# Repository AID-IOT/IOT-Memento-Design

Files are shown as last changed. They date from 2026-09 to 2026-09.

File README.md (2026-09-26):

# Memento

A keepsake PCB built at the **AICTE IDEA Lab, Poornima College of Engineering**.
It is a working board as well as a memento: a Seeed XIAO ESP32C3 drives four
WS2812B LEDs and reads a BMP280 pressure/temperature sensor, and serves the
readings on a web page over WiFi. The front silkscreen carries the AICTE IDEA
Lab and Poornima College logos.

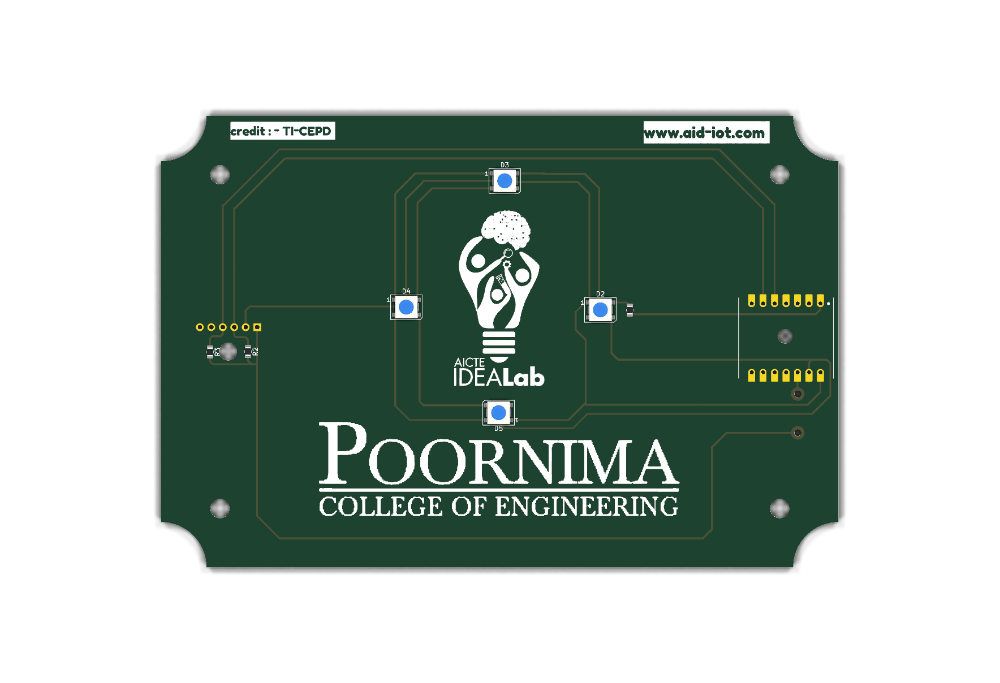
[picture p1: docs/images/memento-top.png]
Memento board, top side - 3D render of the finished PCB showing the AICTE IDEA Lab and Poornima College of Engineering logos on the front silkscreen


| | |
|---|---|
| Board | 150 × 100 mm, 1.6 mm, 2-layer |
| Controller | Seeed Studio XIAO ESP32C3 (RISC-V, WiFi 4 + BLE 5) |
| LEDs | 4 × WS2812B (5050 PLCC-4), daisy-chained |
| Sensor | GY-BMP280-3.3 module, I²C |
| Mounting | 4 × ⌀4.25 mm holes, 13 mm in from each edge |

## Repository layout

```
memento/
├── hw/          KiCad 10 project — schematic, PCB, project library, logo art
│   ├── memento.kicad_sch / .kicad_pcb / .kicad_pro
│   ├── memento.kicad_sym         project symbols
│   ├── memento.pretty/           project footprints
│   ├── assets/                   logo source images
│   └── tools/                    helper scripts (IPC, logo → footprint)
├── sw/          Firmware — builds in PlatformIO *and* opens in Arduino IDE
│   ├── platformio.ini
│   └── memento_fw/
│       ├── memento_fw.ino
│       ├── config.h              ← WiFi name and password go here
│       └── index_html.h          the web page
├── docs/        Project manual (.docx)
│   └── images/                   board renders used in this README
└── README.md
```

## Quick start

**1. Flash the board.** Plug the XIAO into USB-C, then either:

- *Arduino IDE* — open `sw/memento_fw/memento_fw.ino`, select board
  **XIAO_ESP32C3**, install the four Adafruit libraries, upload.
- *PlatformIO* — from `sw/`, run `pio run -t upload`.

Full steps, including the board-manager URL and library list, are in
[`sw/README.md`](sw/README.md).

**2. Set your WiFi.** Before uploading, edit `sw/memento_fw/config.h`:

```c
#define WIFI_SSID       "YOUR_WIFI_NAME"
#define WIFI_PASSWORD   "YOUR_WIFI_PASSWORD"
```

If that network cannot be joined the board starts its own hotspot
(`memento-setup` / `memento123`) so the page is still reachable.

**3. Open the page.** Open the serial monitor at **115200 baud**. It prints the
address it got:

```
Connected. Open http://192.168.1.42/  (or http://memento.local/)
BMP280 found at 0x76
HTTP server up on port 80
```

Browse to that address from any device on the same network. The page shows
temperature, pressure and altitude, refreshing every 2 seconds, and lets you set
the LED mode, colour, brightness and speed.

## Pin map

Taken from `hw/memento.kicad_sch`:

| Signal | XIAO pin | GPIO | Connects to |
|---|---|---|---|
| WS2812B data | D0 | 2 | R1 → D2.DIN → D3 → D4 → D5 |
| I²C SDA | D4 | 6 | U2.SDA, pulled up by R3 |
| I²C SCL | D5 | 7 | U2.SCL, pulled up by R2 |
| +5 V | 5V | — | WS2812B VDD ×4 |
| +3.3 V | 3V3 | — | BMP280 VCC, R2/R3 pull-ups |
| GND | GND | — | all |

## Bill of materials

| Ref | Qty | Part | Package | Notes |
|---|---|---|---|---|
| U1 | 1 | Seeed XIAO ESP32C3 | 14-pin module, 2.54 mm | Hybrid land pattern: headers or castellations |
| U2 | 1 | GY-BMP280-3.3 module | 6-pin, 2.54 mm | Runs from 3V3 |
| D2–D5 | 4 | WS2812B | 5050 PLCC-4 | Addressable RGB |
| R1 | 1 | 330 Ω | 0805 | Series on LED data line |
| R2, R3 | 2 | 4.7 kΩ | 0805 | I²C pull-ups to 3V3 |

> The resistor value fields in the schematic are still at their default
> (`R_US`). The values above are the intended ones — set them in the schematic
> before generating fabrication files.

## Building the PCB

Open `hw/memento.kicad_pro` in **KiCad 10**. The project carries its own symbol
and footprint libraries (`memento.kicad_sym`, `memento.pretty/`) registered
through the project-local `sym-lib-table` and `fp-lib-table`, so it opens
standalone with no external library setup.

The full build process — creating symbols, assigning footprints, importing the
logos to silkscreen, placement, routing and checks — is written up step by step
in the manual under [`docs/`](docs/).

The back side carries only the XIAO and BMP280 through-hole pads and the two
signal vias:

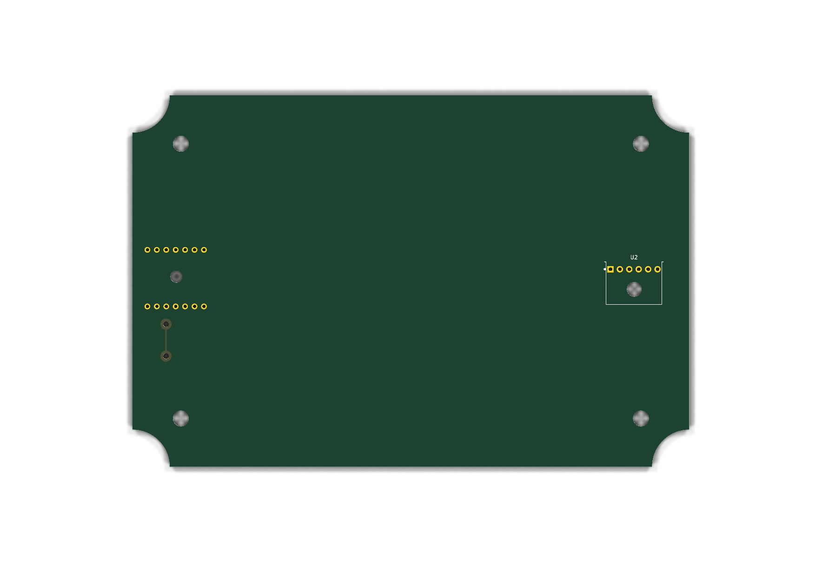
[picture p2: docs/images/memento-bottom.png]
Memento board, bottom side - 3D render showing the through-hole pads and vias


Both renders come straight from the board file, so they can be regenerated after
any layout change:

```bash
kicad-cli pcb render -o docs/images/memento-top.png \
  --side top --preset follow_pcb_editor --quality high \
  --background transparent -w 1800 -h 1240 hw/memento.kicad_pcb
```

Swap `--side top` for `--side bottom` for the other view. The
`follow_pcb_editor` preset matters: the default `follow_plot_settings` drops the
silkscreen, which renders the board as a blank rectangle with no logos.

## Documentation

| File | What it covers |
|---|---|
| [`docs/`](docs/) | Project manual (.docx) — full KiCad workflow, BOM, programming, usage |
| [`sw/README.md`](sw/README.md) | Firmware setup, libraries, HTTP API, hardware notes |

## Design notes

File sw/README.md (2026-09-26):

# memento — firmware

Firmware for the memento board: a **Seeed XIAO ESP32C3** driving **4× WS2812B**
LEDs and reading a **GY-BMP280-3.3** pressure/temperature module. It joins your
WiFi and serves a web page with the live readings and LED controls.

The same folder works two ways — open it in the Arduino IDE, or build it with
PlatformIO. Nothing needs converting.

```
sw/
├── platformio.ini        PlatformIO config (points src_dir at the sketch folder)
└── memento_fw/
    ├── memento_fw.ino    the sketch
    └── config.h          WiFi name/password and startup settings — edit this
```

## 1. Set your WiFi

Open `memento_fw/config.h` and change these two lines:

```c
#define WIFI_SSID       "YOUR_WIFI_NAME"
#define WIFI_PASSWORD   "YOUR_WIFI_PASSWORD"
```

If the board cannot join that network it starts its own hotspot instead
(`memento-setup`, password `memento123`), so the page is still reachable.
Both are configurable in the same file.

## 2a. Arduino IDE

1. **File → Preferences → Additional boards manager URLs**, add:
   `https://raw.githubusercontent.com/espressif/arduino-esp32/gh-pages/package_esp32_index.json`
2. **Tools → Board → Boards Manager**, install **esp32** by Espressif Systems.
3. **Tools → Board → ESP32 Arduino → XIAO_ESP32C3**.
4. **Tools → Manage Libraries**, install:
   - Adafruit NeoPixel
   - Adafruit BMP280 Library
   - Adafruit Unified Sensor
   - Adafruit BusIO
5. Open `memento_fw/memento_fw.ino`, edit `config.h`, upload.

## 2b. PlatformIO

From this `sw/` folder — libraries download automatically:

```
pio run              # build
pio run -t upload    # build and flash
pio device monitor   # serial log, 115200
```

## 3. Open the page

After upload, open the serial monitor at **115200**. It prints the address:

```
Joining "YOUR_WIFI_NAME" ....
Connected. Open http://192.168.1.42/  (or http://memento.local/)
BMP280 found at 0x76
HTTP server up on port 80
```

The page shows temperature, pressure and altitude (refreshing every 2 s) and
lets you set the LED mode, colour, brightness and animation speed.

## Pin map

Taken from the schematic (`../hw/memento.kicad_sch`), not assumed:

| Signal | XIAO pin | GPIO | Goes to |
|---|---|---|---|
| WS2812B data | D0 | **2** | R1 → D2.DIN → D3 → D4 → D5 (4 LEDs) |
| I²C SDA | D4 | **6** | U2 (BMP280) SDA |
| I²C SCL | D5 | **7** | U2 (BMP280) SCL |
| Power | 5V / GND | — | LEDs and sensor module |

## HTTP endpoints

| Route | Purpose |
|---|---|
| `GET /` | the control page |
| `GET /api/status` | JSON: sensor readings, LED state, network, uptime |
| `GET /api/led` | set LEDs — `mode`, `r`, `g`, `b`, `brightness`, `speed` |

`mode` is one of `solid`, `rainbow`, `breathe`, `chase`, `off`.
Example:

```
curl "http://memento.local/api/led?mode=solid&r=255&g=80&b=0&brightness=120"
```

## Notes on the hardware

- **The BMP280 module's VCC is wired to +5V on this board.** The GY-BMP280-**3.3**
  variant is a 3.3 V part with no on-board regulator, and the BMP280 is not 5 V
  tolerant. Check your module before powering it: if it has no regulator, move
  VCC to the XIAO's 3V3 pin. The firmware cannot protect against this.
- **CSB (pin 5) and SDO (pin 6) of the module are left unconnected.** Most
  GY-BMP280 boards pull CSB high (selects I²C) and SDO low (address `0x76`)
  with on-board resistors, so this usually works. The firmware probes `0x76`
  then `0x77` and keeps retrying every 5 s, so a late or intermittent sensor
  recovers without a reset. If it is never detected, tie CSB to VCC.
- The WS2812B chain runs at 5 V while the XIAO's data output is 3.3 V. That is
  below the 0.7 × VDD input threshold in the datasheet. It commonly works, and
  R1 sits in series on the data line, but a level shifter is the in-spec fix if
  the first LED misbehaves.
- GPIO2 is a strapping pin on the ESP32-C3. The WS2812B data input is
  high-impedance so it does not disturb boot mode.

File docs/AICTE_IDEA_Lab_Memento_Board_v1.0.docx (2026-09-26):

AICTE IDEA Lab Memento Board

v1.0

Project - Memento

From

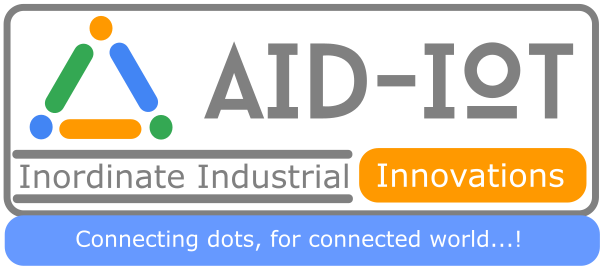
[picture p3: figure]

www.aid-iot.com

Inordinate Industrial Innovations Pvt Ltd.

BP-5, MLU Plots, DDA, Bindapur, Dwarka, New Delhi, 110059

Table of Contents

# 1. Introduction

The Memento is a keepsake circuit board built at the AICTE IDEA Lab, Poornima College of Engineering. It is a real working board as well as a souvenir: a Seeed Studio XIAO ESP32C3 module drives four addressable WS2812B RGB LEDs and reads air pressure and temperature from a BMP280 sensor module. The board joins a WiFi network and publishes the sensor readings on a small web page, which also lets you change the LED colour and animation from a phone or laptop.

The front of the board carries the AICTE IDEA Lab and Poornima College of Engineering logos in silkscreen.

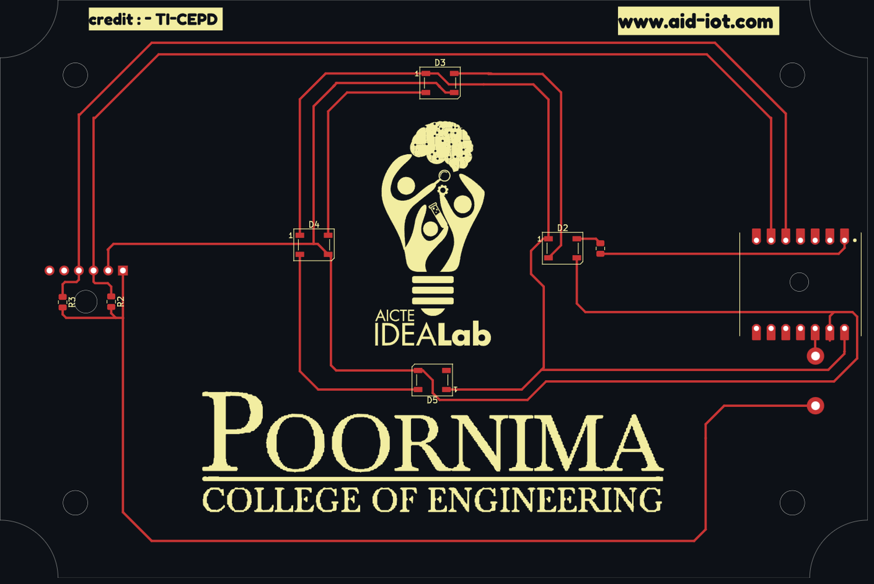
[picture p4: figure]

Front copper, silkscreen and board outline

## 1.1 Board summary

Item | Detail
Board size | 150 x 100 mm, 1.6 mm thick, 2 layers
Controller | Seeed Studio XIAO ESP32C3 (RISC-V, WiFi 4, BLE 5)
LEDs | 4 x WS2812B, 5050 PLCC-4, daisy chained
Sensor | GY-BMP280-3.3 module, I2C, pressure and temperature
Mounting | 4 x 4.25 mm holes, 13 mm in from every edge
Design tool | KiCad 10
Firmware | Arduino / ESP32 core, builds in Arduino IDE or PlatformIO

## 1.2 What you need

- KiCad 10 or newer, to open and edit the hardware design.
- Arduino IDE 2.x, or Visual Studio Code with the PlatformIO extension, to build the firmware.
- A USB-C cable that carries data, not a charge-only cable.
- A 2.4 GHz WiFi network. The ESP32-C3 does not support 5 GHz networks.
- A soldering iron and the parts in the bill of materials in section 4.2.

# 2. Repository Layout

The project is split into hardware, software and documentation:

memento/

hw/ KiCad project

memento.kicad_sch schematic

memento.kicad_pcb board layout

memento.kicad_pro project file - open this one

memento.kicad_sym project symbol library

memento.pretty/ project footprint library

assets/ logo source images

tools/ helper scripts

sw/ firmware

platformio.ini

memento_fw/

memento_fw.ino the sketch

config.h WiFi name and password

index_html.h the web page

docs/ this manual

README.md

Note The KiCad project carries its own symbol and footprint libraries, registered through the project-local sym-lib-table and fp-lib-table files. It opens on any machine with no extra library setup.

# 3. Hardware Design in KiCad

This section walks through how the board was built, in the order the work was done. Follow the same sequence to reproduce it or to make your own variant.

## 3.1 Opening the project

1. Start KiCad.
2. Choose File > Open Project.
3. Browse to the hw folder and open memento.kicad_pro.
4. The project manager lists the schematic and the PCB. Double-click either to open its editor.

## 3.2 Creating a schematic symbol

A symbol is the drawing of a part on the schematic, with its pins and pin numbers. KiCad ships thousands of symbols, but modules such as the XIAO ESP32C3 and the BMP280 breakout are not included, so they were drawn for this project and saved in the project library.

To create one:

5. In the schematic editor, choose Tools > Symbol Editor.
6. In the Libraries pane, select the project library (memento). If it is not listed, add it first with Preferences > Manage Symbol Libraries > Project Specific Libraries.
7. Choose File > New Symbol. Give it a name and a reference designator prefix - U for modules and integrated circuits, D for LEDs, R for resistors.
8. Draw the body with Place > Rectangle.
9. Add pins with Place > Pin. For every pin set the number, the name and the electrical type. The number must match the footprint pad number exactly, because that is the only link between the two.
10. Save the symbol.

Note Electrical type matters. Power inputs marked as Power Input, outputs as Output, and so on, are what lets the Electrical Rules Check catch mistakes such as two outputs driven onto the same net.

The symbols in this project and their pin numbering:

Symbol | Pins | Pin numbering
XIAO_ESP32C3 | 14 | 1-7 down the left edge (D0-D6), 8-14 up the right edge (D7-D10, 3V3, GND, 5V)
WS2812B | 4 | 1 VDD, 2 DOUT, 3 VSS, 4 DIN
BMP280_Module | 6 | 1 VCC, 2 GND, 3 SCL, 4 SDA, 5 CSB, 6 SDO

## 3.3 Creating a footprint

A footprint is the physical pattern of copper pads, silkscreen and courtyard that the part sits on. It must match the real part, so always work from the manufacturer drawing rather than from memory.

11. In the PCB editor, choose Tools > Footprint Editor.
12. Select the project library (memento) and choose File > New Footprint.
13. Place pads with Place > Pad. Set the pad number to match the symbol pin number, and set the shape, size and drill.
14. Draw the part outline on the F.Silkscreen layer, and the true body size on F.Fab.
15. Draw a courtyard on F.CrtYd, slightly larger than the part, so KiCad can warn when parts overlap.
16. Mark pin 1 clearly - a dot, a square pad or a chamfered corner.
17. Save the footprint.

The footprints used here:

Footprint | Type | Key dimensions
XIAO-ESP32C3-Hybrid | Through-hole + SMD | 14 holes, 2.54 mm pitch, 15.24 mm between rows, 0.889 mm drill, plus castellation pads
WS2812B_PLCC4_5.0x5.0mm | SMD | 4 pads 1.5 x 0.9 mm, body 5.0 x 5.0 mm
BMP280_Module_GY_6P_15x11.5mm | Through-hole | 6 holes, 2.54 mm pitch, 1.0 mm drill, outline 15 x 11.5 mm
R_0805_2012Metric | SMD | Standard KiCad 0805 land pattern

Note The XIAO footprint is a hybrid: every pin has a plated through-hole for header mounting and an outboard SMD pad for the castellated edge, so the module can be socketed or soldered flat.

## 3.4 Assigning footprints to symbols

Each symbol on the schematic must be told which footprint to use. There are two ways:

### Using the symbol properties

18. In the schematic, double-click the symbol.
19. Click the Footprint field, then the library browser button at the right.
20. Pick the footprint and click OK.

### Using the assignment tool

21. In the schematic editor, choose Tools > Assign Footprints.
22. The left pane lists libraries, the middle lists symbols, the right lists footprints.
23. Select a symbol, then double-click the footprint to assign it.
24. Click Apply, Save Schematic & Continue.

Note If you set a Footprint field inside the library symbol itself, every new copy you place already has the correct footprint and no assignment step is needed. That is how the symbols in this project are set up.

## 3.5 Importing an image onto the silkscreen

The two logos on this board were imported from ordinary image files. KiCad includes a converter for exactly this.

### Using the KiCad Image Converter

25. From the KiCad project manager, choose Tools > Image Converter.
26. Click Load Source Image and select the picture. PNG works well. A high-contrast image gives the best result.
27. Look at the Greyscale and Black and White preview tabs. Adjust the Threshold slider until the shape is clean and the detail you want is still visible.
28. Set the output size, either by entering the DPI or by setting the size in millimetres. Check the aspect ratio lock so the image is not stretched.
29. Under Output Format choose Footprint (.kicad_mod).
30. Under Board Layer for Outline choose Front Silkscreen.
31. Click Export to File and save the result inside your project footprint library folder, memento.pretty. KiCad only loads footprints that sit inside a folder listed in fp-lib-table, so a file saved anywhere else - the project root included - will not be found.
32. In the PCB editor, choose Place > Place Footprints (shortcut A), pick the new footprint from the memento library and click to place it. On KiCad 8 and earlier the same command is named Add Footprint.

Two things to fix after placing a logo footprint:

- Open its properties and tick "Not in schematic" (the board-only attribute), together with "Exclude from bill of materials" and "Exclude from position files". Without this, Update PCB from Schematic will offer to delete the logo because it has no matching symbol.
- Check the smallest details against your fabricator's minimum silkscreen line width, usually about 0.15 mm. Fine lines below that fill in when printed, so scale the logo up if detail is being lost.

Note The converter is monochrome. A colour logo becomes a single-colour silhouette: everything that is not background becomes ink, and enclosed background areas become gaps. Check the preview to confirm the result still reads correctly.

### If the new footprint does not appear in the chooser

Two causes account for nearly every case.

33. The file was saved outside the library folder. The Image Converter reuses the last folder you exported to, which is often the project root. A loose .kicad_mod file is never picked up on its own; move it into memento.pretty and it appears in the chooser under the memento library.
34. The library cache is stale. KiCad keeps an fp-info-cache file beside the project and does not always notice footprints added from outside the editor. Open Preferences > Manage Footprint Libraries and click OK to force a rescan, or close and reopen the PCB editor.

Note KiCad names the library entry after the file, not after the name written inside it. A file saved as aid_iot_logo.kicad_mod is listed as aid_iot_logo even though the converter wrote (footprint "LOGO") on the first line. Rename the two to match so the library stays readable.

### Putting a logo on the schematic

The same converter can emit a schematic symbol instead: choose Symbol (.kicad_sym) under Output Format and export. A symbol library is a single .kicad_sym file rather than a folder, and it has to be registered before the symbol chooser will list it. In the schematic editor open Preferences > Manage Symbol Libraries, add the file on the Project Specific Libraries tab and give it a nickname; this writes a line into sym-lib-table beside the project.

A logo symbol has no pins. Mark it Exclude from bill of materials and Exclude from board in its properties so it never reaches the netlist.

### Cleaner outlines with logo2fp.py

The Image Converter works from a black and white threshold, which rounds off fine detail. This project also carries hw/tools/logo2fp.py, which traces the ink boundary directly and writes one filled polygon per outline, folding enclosed gaps back into their parent shape. It holds edges better at small sizes. Run it from the hw folder:

python tools/logo2fp.py assets/logo_poornima.png \

memento.pretty/Logo_Poornima_80x48.kicad_mod \

Logo_Poornima_80x48 80.0 400 F.SilkS 5:3

The arguments are the source image, the output path, the footprint name and the width in millimetres, followed by the optional trace resolution, target layer and box aspect ratio. Both logos already on this board were produced this way. The script needs numpy and Pillow.

### Placing an image for reference only

If you only want a picture as a guide - a mechanical drawing or a layout sketch - use Place > Place Reference Images in the PCB or schematic editor (named Add Image on KiCad 8 and earlier). Reference images are shown in the editor but are not plotted to the fabrication outputs, so they never appear on the finished board.

## 3.6 Updating the PCB from the schematic

The schematic is the source of truth. The board is brought into line with it rather than edited independently.

35. Draw the circuit in the schematic editor. Place symbols with Place > Add Symbol, wire them with Place > Wire, and add power symbols for the supply nets.
36. Annotate the sheet with Tools > Annotate Schematic so every part gets a unique reference designator.
37. Run the Electrical Rules Check with Inspect > Electrical Rules Checker and clear anything real.
38. Save the schematic.
39. In the PCB editor choose Tools > Update PCB from Schematic, or press F8.
40. Review the list of changes and click Update PCB. New footprints appear at the cursor for you to place.

Note KiCad links each symbol to its footprint by a hidden unique identifier, not by the reference designator. That is why renaming a part does not break the link, and why a footprint added directly to the board with no symbol behind it must be marked board-only.

## 3.7 Component placement

Placement decides how easy the routing will be. Work from the fixed constraints outwards.

41. Place the parts whose position is dictated by the enclosure or by the user first. Here the XIAO sits at the right-hand edge so the USB-C connector is reachable.
42. Place the parts that must sit near something else. The pull-up resistors R2 and R3 sit next to the BMP280 module, and the series resistor R1 sits next to the XIAO data pin.
43. Place the decorative elements - here the two logos and the text labels - and keep them clear of the parts.
44. Spread the four WS2812B LEDs around the logo so the light is even.
45. Use Edit > Properties or the Position fields to set exact coordinates where symmetry matters.

Useful tools while placing:

- Press M to move a part, R to rotate it, F to flip it to the other side of the board.
- The ratsnest - the thin lines showing what still needs connecting - shows when a move will make routing shorter.
- View > Grid, and the grid selector in the toolbar, keep parts on tidy coordinates.
- Inspect > Design Rules Checker reports courtyard overlaps if two parts are placed too close.

## 3.8 Routing

Routing draws the copper tracks that carry the signals.

46. Select the copper layer to work on in the Layers pane - F.Cu for the front, B.Cu for the back.
47. Choose Route > Route Single Track, or press X, then click a pad to start.
48. Click to place corners and double-click to finish on the destination pad. The ratsnest line for that connection disappears once it is routed.
49. Press V while routing to drop a via and continue on the other layer.
50. Set track widths under File > Board Setup > Design Rules > Net Classes. Power nets are usually given wider tracks than signals.
51. When everything is routed, run the Design Rules Checker and confirm there are no unconnected items left.

Guidance that applies to this board:

- Give the +5 V and GND tracks more width than the signal tracks. They carry the LED current, which rises with brightness.
- Keep the WS2812B data chain going in one direction: XIAO to D2, D2 to D3, D3 to D4, D4 to D5. Each LED regenerates the signal for the next.
- Keep the I2C pair SDA and SCL reasonably short and run them together.
- Leave clearance around the mounting holes so a screw head or standoff cannot touch copper.

## 3.9 Board outline and mounting holes

The board shape is drawn on the Edge.Cuts layer. Anything on that layer is cut by the fabricator.

52. Select the Edge.Cuts layer.
53. Draw the outline with Place > Line, Place > Rectangle or Place > Arc. It must form one closed shape with no gaps.
54. For mounting holes, either place a circle on Edge.Cuts, or place a mounting-hole footprint from the KiCad MountingHole library if you want a plated hole with a pad.
55. Check the result with View > 3D Viewer, which shows the board exactly as it will be cut.

This board is 150 x 100 mm with rounded inside corners and four mounting holes of 4.25 mm diameter, each set 13 mm in from both nearest edges so the pattern is symmetric about the centre of the board.

## 3.10 Electrical and design rule checks

Two separate checks must both be clean before sending the board out.

### Electrical Rules Check - the schematic

56. In the schematic editor choose Inspect > Electrical Rules Checker.
57. Click Run ERC.
58. Work through each message. Common ones are unconnected pins, and power input pins with nothing driving them - which is normal until you add power flags.

### Design Rules Check - the board

59. In the PCB editor choose Inspect > Design Rules Checker.
60. Tick "Report all errors for tracks" and click Run DRC.
61. Fix clearance violations, unconnected items and silkscreen overlaps.
62. Pay attention to "unconnected items". Any number other than zero means part of the circuit is not routed.

Note Set the clearance and track width rules to match your fabricator before routing, under File > Board Setup > Design Rules > Constraints. Fixing a board designed to the wrong rules is far more work than setting them first.

## 3.11 Fabrication outputs

When both checks are clean, produce the files the factory needs.

63. Choose File > Fabrication Outputs > Gerbers. Select the layers and export to a gerbers folder.
64. Choose File > Fabrication Outputs > Drill Files and export into the same folder.
65. Zip the folder and send it to the fabricator.
66. For assembly, also export the position file from File > Fabrication Outputs > Component Placement, and the bill of materials from the schematic editor with Tools > Generate BOM.

# 4. Project Details

## 4.1 Pin map

These are the actual connections in the schematic. The firmware uses exactly these pins.

Signal | XIAO pin | GPIO | Connects to
WS2812B data | D0 | 2 | R1, then D2.DIN, then D3, D4, D5 in a chain
I2C SDA | D4 | 6 | U2 SDA, pulled up to 3V3 by R3
I2C SCL | D5 | 7 | U2 SCL, pulled up to 3V3 by R2
+5 V | 5V | - | VDD of all four WS2812B LEDs
+3.3 V | 3V3 | - | BMP280 VCC and the two I2C pull-ups
GND | GND | - | Every part

Note The BMP280 module runs from 3.3 V, not 5 V. The GY-BMP280-3.3 has no on-board regulator and the BMP280 is not 5 V tolerant, so connecting it to 5 V damages it.

## 4.2 Bill of materials

Ref | Qty | Part | Package | Notes
U1 | 1 | Seeed Studio XIAO ESP32C3 | 14-pin module, 2.54 mm | Headers or castellated mounting
U2 | 1 | GY-BMP280-3.3 module | 6-pin, 2.54 mm | Pressure and temperature, I2C
D2, D3, D4, D5 | 4 | WS2812B | 5050 PLCC-4 | Addressable RGB LED
R1 | 1 | 330 ohm | 0805 | Series resistor on the LED data line
R2, R3 | 2 | 4.7 k ohm | 0805 | I2C pull-ups to 3V3
- | 4 | M4 screw and standoff | - | For the 4.25 mm mounting holes
- | 1 | USB-C cable | - | Must carry data, not charge only

Note The resistor value fields in the schematic are still at their default and read R_US. The values above are the intended ones - set them in the schematic before generating fabrication files or before ordering parts.

## 4.3 Assembly notes

67. Solder the four WS2812B LEDs first. They are surface mount and easiest to reach while the board is otherwise empty. Watch the orientation - the cut corner or the marking on the package matches pin 1 on the footprint.
68. Solder the three 0805 resistors.
69. Fit a 7-pin header strip on each side for the XIAO, or solder the module directly onto the castellated pads.
70. Fit a 6-pin header for the BMP280 module.
71. Check for solder bridges before applying power, especially across the fine-pitch LED pads.
72. Power the board over USB-C and confirm the LEDs light before going further.

# 5. Programming the Board

The firmware lives in the sw folder. It is written so that the same files open in the Arduino IDE and build under PlatformIO, with nothing to convert between them.

## 5.1 Firmware layout

File | Purpose
sw/platformio.ini | PlatformIO settings. Points at the sketch folder so both tools share one copy of the code.
sw/memento_fw/memento_fw.ino | The sketch - setup, main loop, sensor reading, LED animation and web server.
sw/memento_fw/config.h | WiFi name and password, and the start-up LED settings. This is the file you edit.
sw/memento_fw/index_html.h | The web page, stored as text in program memory.

## 5.2 Setting the WiFi name and password

Open sw/memento_fw/config.h and change these two lines:

#define WIFI_SSID "YOUR_WIFI_NAME"

#define WIFI_PASSWORD "YOUR_WIFI_PASSWORD"

If the board cannot join that network within 20 seconds it starts its own hotspot instead, so the page is still reachable:

#define AP_SSID "memento-setup"

#define AP_PASSWORD "memento123"

Connect a phone or laptop to that hotspot and open http://192.168.4.1/ to reach the page.

Note The ESP32-C3 only joins 2.4 GHz networks. If your router broadcasts one name for both 2.4 GHz and 5 GHz, and the board will not connect, try a separate 2.4 GHz network name or a phone hotspot set to 2.4 GHz.

## 5.3 Method A - Arduino IDE

### One-time setup

73. Open File > Preferences.
74. In "Additional boards manager URLs" paste: https://raw.githubusercontent.com/espressif/arduino-esp32/gh-pages/package_esp32_index.json
75. Click OK, then open Tools > Board > Boards Manager.
76. Search for esp32 and install "esp32 by Espressif Systems".
77. Open Tools > Manage Libraries and install these four: Adafruit NeoPixel, Adafruit BMP280 Library, Adafruit Unified Sensor, Adafruit BusIO.

### Every time

78. Open sw/memento_fw/memento_fw.ino. The Arduino IDE shows config.h and index_html.h as extra tabs, because they sit in the same folder as the sketch.
79. Edit the WiFi name and password on the config.h tab.
80. Choose Tools > Board > ESP32 Arduino > XIAO_ESP32C3.
81. Plug in the board and choose its port under Tools > Port.
82. Click Upload.

Note If no port appears, hold the BOOT button on the XIAO, tap RESET, then release BOOT. The board enters its bootloader and the port appears. Also check the USB cable carries data - charge-only cables are a common cause.

## 5.4 Method B - PlatformIO

From the sw folder. PlatformIO downloads the toolchain and the libraries by itself on the first build.

pio run build only

pio run -t upload build and flash the board

pio device monitor open the serial log at 115200 baud

In Visual Studio Code, open the sw folder and use the PlatformIO toolbar buttons at the bottom of the window instead of typing the commands.

# 6. Checking the Web Page

## 6.1 Finding the address

83. Keep the board plugged into USB after uploading.
84. Open the serial monitor - in the Arduino IDE, Tools > Serial Monitor; in PlatformIO, pio device monitor.
85. Set the speed to 115200 baud.
86. Press the RESET button on the XIAO so you see the start-up messages from the beginning.

You should see something like this:

memento starting

BMP280 found at 0x76

Joining "YOUR_WIFI_NAME" ....

Connected. Open http://192.168.1.42/ (or http://memento.local/)

HTTP server up on port 80

87. Type that address into a browser on any device connected to the same network.

Note http://memento.local/ works on most phones and on Windows, macOS and Linux machines with mDNS. If it does not resolve on your network, use the numeric address instead - it always works.

## 6.2 What the page shows

The page has two parts.

The BMP280 panel shows three live readings, refreshed every two seconds:

- Temperature, in degrees Celsius.
- Pressure, in hectopascal.
- Altitude, in metres. This is calculated from the pressure, so it is only as accurate as the sea-level pressure set in config.h.

If the sensor is not detected the panel turns amber and the readings show as dashes. The firmware keeps retrying every five seconds, so a loose module starts working again as soon as it is reseated, without a reset.

The WS2812B panel controls the four LEDs:

Control | What it does
Solid | All four LEDs show the chosen colour
Rainbow | Colours cycle smoothly around the chain
Breathe | The chosen colour fades up and down
Chase | A bright dot runs around the chain
Off | All LEDs off
Colour | Colour picker, used by Solid, Breathe and Chase
Brightness | 0 to 255
Speed | Milliseconds per animation step - lower is faster

The line at the bottom of the page shows whether the board is on your WiFi or running its own hotspot, its address, the signal strength, how long it has been running, and the sensor address.

## 6.3 HTTP API

The page is driven by two simple endpoints, which you can also call yourself for testing or to connect the board to something else.

Route | Purpose
GET / | The control page
GET /api/status | JSON with the sensor readings, LED state, network details and uptime
GET /api/led | Sets the LEDs. Parameters: mode, r, g, b, brightness, speed

For example, to set all four LEDs to solid orange at medium brightness:

curl "http://memento.local/api/led?mode=solid&r=255&g=80&b=0&brightness=120"

And to read the sensor from a script:

curl http://memento.local/api/status

# 7. Troubleshooting

Symptom | What to check
No serial port appears | Use a data USB cable. Hold BOOT, tap RESET, release BOOT to force the bootloader.
Upload fails part way | Close the serial monitor first - it holds the port open. Then retry.
Board never joins WiFi | The network must be 2.4 GHz. Check the name and password for typing mistakes and stray spaces. Watch the serial log for the reason.
Page will not open | Use the numeric address from the serial log rather than memento.local. Confirm your phone or laptop is on the same network.
BMP280 not detected | The serial log reports it at start-up. Check the 6-pin header solder joints, that VCC goes to 3V3, and that CSB is not pulled low. The firmware probes both 0x76 and 0x77.
Sensor readings look wrong | Altitude depends on SEA_LEVEL_HPA in config.h. Set it to your local sea-level pressure for a meaningful altitude.
LEDs stay dark | Check the brightness is not zero and the mode is not Off. Confirm 5 V reaches the first LED and that R1 is fitted.
Only the first LED works | The chain is broken after it. Check the DOUT to DIN joint between that LED and the next.
LED colours are wrong or flicker | The data line runs at 3.3 V into 5 V parts, which is below the datasheet threshold. It usually works, but a level shifter is the proper fix.

Inordinate Industrial Innovations Pvt Ltd.

Restricted www.aid-iot.com

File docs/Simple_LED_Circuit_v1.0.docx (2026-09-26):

Simple LED Circuit

v1.0

Project - Memento

From


www.aid-iot.com

Inordinate Industrial Innovations Pvt Ltd.

BP-5, MLU Plots, DDA, Bindapur, Dwarka, New Delhi, 110059

Table of Contents

# 1. Aim

To build a simple series circuit in which a single light emitting diode (LED) is lit from an external power supply, with the current limited by one series resistor, and to verify the resistor value by measurement and calculation.

# 2. Components Required

Ref | Qty | Component | Specification
D1 | 1 | LED, 5 mm | Red, forward voltage about 2.0 V, forward current 10 to 20 mA
R1 | 1 | Resistor | 330 ohm, 1/4 W, 5 percent tolerance
J1 | 1 | 2-pin screw terminal | 5.08 mm pitch, for the power input wires
- | 1 | Regulated DC supply | 5 V, current limit set to 100 mA if available
- | 1 | Digital multimeter | For voltage and current measurement
- | 1 | Breadboard and jumper wires | Or stripboard, for trial assembly

Note The 330 ohm value assumes a 5 V supply and a red LED. Section 3.3 shows how to work out the correct value for any supply voltage and LED colour.

# 3. Theory

## 3.1 How an LED works

A light emitting diode is a semiconductor diode that emits light when current flows through it in the forward direction. Like any diode it conducts in one direction only. The two leads are not interchangeable:

- The anode (A) is the positive lead. On a new LED it is the longer lead.
- The cathode (K) is the negative lead. It is the shorter lead, and the plastic body is flattened on that side.

Connected the right way round the LED conducts and lights. Connected backwards it blocks current and stays dark, and in this low-voltage circuit no harm is done - simply turn it around.

## 3.2 Why a series resistor is essential

An LED is a current-operated device, not a voltage-operated one. Once the supply reaches the forward voltage, the current through the LED rises extremely steeply for a very small further increase in voltage. A red LED that drops about 2.0 V at 10 mA may pass several hundred milliamperes at 2.2 V.

If an LED is connected straight across a 5 V supply, nothing limits that current except the internal resistance of the supply and the leads. The current rises far beyond the rated 20 mA and the LED is destroyed, usually within a second.

The series resistor solves this. It takes up the difference between the supply voltage and the LED forward voltage, and because a resistor obeys Ohm’s law, that voltage difference across a known resistance sets a predictable current.

Note Never connect an LED directly across a power supply without a series resistor. This is the single most common way of destroying an LED.

## 3.3 Choosing the resistor value

Apply Kirchhoff’s voltage law around the loop. The supply voltage equals the voltage across the resistor plus the voltage across the LED:

Vs = V_R + V_f

so V_R = Vs - V_f

The resistor and the LED are in series, so the same current flows through both. From Ohm’s law:

Vs - V_f

R = ------------

I

For this experiment, with a 5 V supply, a red LED of forward voltage 2.0 V and a chosen current of 10 mA:

R = (5.0 - 2.0) / 0.010

= 3.0 / 0.010

= 300 ohm

300 ohm is not a standard value, so the next standard value above it is used. Choosing the next value up is deliberate: a slightly larger resistor gives slightly less current, which is safe. A smaller one gives more current, which is not.

Standard value chosen: R1 = 330 ohm

Actual current = (5.0 - 2.0) / 330

= 0.00909 A

= 9.09 mA

Check the power the resistor must dissipate, so that a 1/4 W part is adequate:

P_R = I^2 x R

= (0.00909)^2 x 330

= 0.0273 W = 27.3 mW

27.3 mW is well under the 250 mW rating of a 1/4 W resistor, so the part will not even feel warm.

The table below gives the calculation for other common combinations, all at a target current of 10 mA:

Supply | LED colour | V_f (typical) | Calculated R | Standard value
5 V | Red | 2.0 V | 300 ohm | 330 ohm
5 V | Yellow / green | 2.2 V | 280 ohm | 330 ohm
5 V | Blue / white | 3.2 V | 180 ohm | 220 ohm
3.3 V | Red | 2.0 V | 130 ohm | 150 ohm
3.3 V | Blue / white | 3.2 V | 10 ohm | 22 ohm (dim, see note)
12 V | Red | 2.0 V | 1000 ohm | 1 k ohm

Note A blue or white LED on a 3.3 V supply leaves almost no headroom, because the forward voltage is nearly the whole supply. The brightness then varies wildly with small supply changes. Use a 5 V supply for blue and white LEDs.

## 3.4 Reading the resistor colour code

A 1/4 W resistor is marked with four coloured bands. Read from the end where the bands are closest to the lead. The first two bands are digits, the third is the number of zeros to add, and the fourth is the tolerance.

Value | Band 1 | Band 2 | Band 3 (multiplier) | Band 4 (tolerance)
150 ohm | Brown (1) | Green (5) | Brown (x10) | Gold (5 percent)
220 ohm | Red (2) | Red (2) | Brown (x10) | Gold (5 percent)
330 ohm | Orange (3) | Orange (3) | Brown (x10) | Gold (5 percent)
1 k ohm | Brown (1) | Black (0) | Red (x100) | Gold (5 percent)

So the 330 ohm resistor used here reads orange, orange, brown, gold: 3, 3, then one zero, giving 330 ohm at 5 percent tolerance. Always confirm with a multimeter if the colours are hard to judge.

# 4. Circuit Diagram

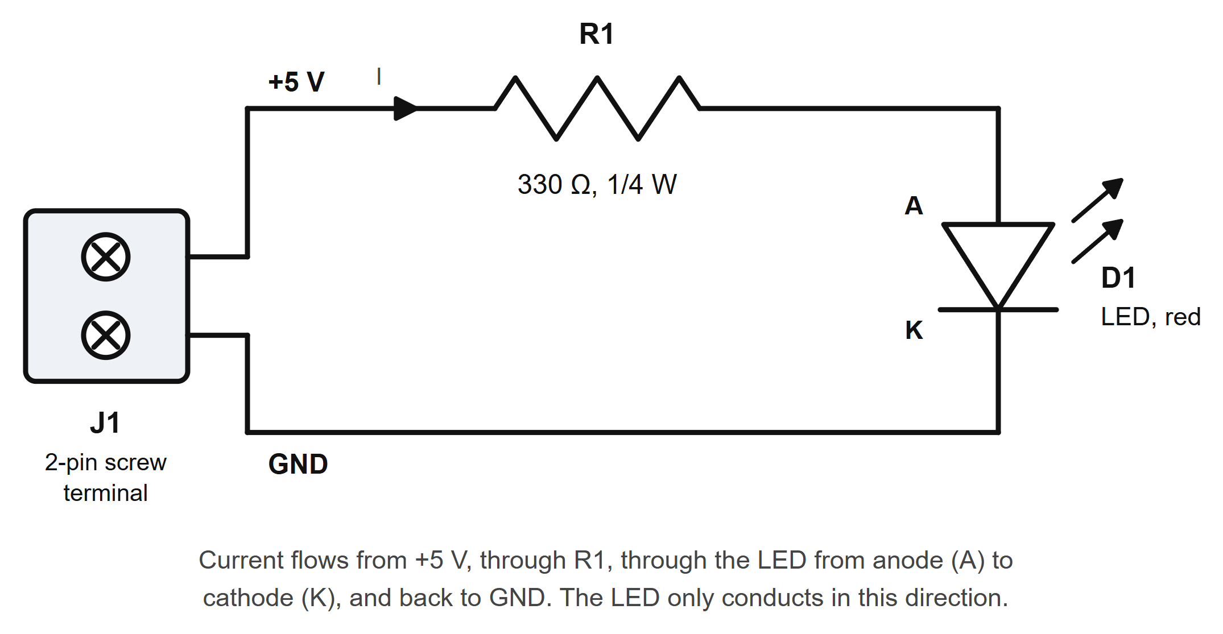
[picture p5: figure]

Figure 1 - LED circuit with series current-limiting resistor

The circuit is a single series loop. Starting at the positive terminal of J1, the current passes through R1, then through D1 from anode to cathode, and returns to the negative terminal of J1. Because it is a series circuit, the same current flows through every component.

# 5. Procedure

## 5.1 Identify the components before wiring

1. Identify the LED leads. The longer lead is the anode (positive). The shorter lead, on the flattened side of the body, is the cathode (negative).
2. Read the resistor colour bands and confirm the value is 330 ohm (orange, orange, brown, gold).
3. Measure the resistor with the multimeter on the resistance range. A 5 percent 330 ohm part should read between 313 and 347 ohm. Record the measured value.
4. Set the bench supply to 5 V with the output switched off. If the supply has an adjustable current limit, set it to about 100 mA.

## 5.2 Build the circuit

5. Place the screw terminal J1 at the edge of the breadboard or stripboard.
6. Connect one wire from the positive terminal of J1 to one end of R1.
7. Connect the other end of R1 to the anode (long lead) of the LED.
8. Connect the cathode (short lead) of the LED back to the negative terminal of J1.
9. Strip about 6 mm of insulation from the two supply wires and clamp them under the screws of J1 - the screw must tighten onto bare copper, not onto insulation.
10. Check the whole loop against Figure 1 before applying power. Confirm in particular that the resistor is in series with the LED and not across it.

## 5.3 Power up and measure

11. Switch on the supply. The LED should light steadily.
12. Measure the supply voltage across J1 and record it as Vs.
13. Measure the voltage across the resistor and record it as V_R.
14. Measure the voltage across the LED and record it as V_f.
15. Calculate the current as I = V_R / R, using your measured resistor value.
16. If the meter has a current range, switch off, break the loop, connect the meter in series, switch on again and compare the measured current with your calculated figure.
17. Switch off the supply before dismantling.

Note To measure current the meter must be in series, which means breaking the circuit. Never place a meter set to a current range across a component - the current range is close to a short circuit and will blow the meter fuse.

# 6. Observations

Record your readings in the table below.

Quantity | Symbol | Measured value | Unit
Resistor value (measured) | R | | ohm
Supply voltage | Vs | | V
Voltage across resistor | V_R | | V
Voltage across LED | V_f | | V
Current, calculated as V_R / R | I | | mA
Current, measured in series | I | | mA
LED state | - | | lit / not lit

# 7. Calculations

Work through the following with your own measured figures.

18. Check Kirchhoff’s voltage law: V_R + V_f should equal Vs. Any small difference is measurement error plus the voltage dropped in the leads.
19. Calculate the current from I = V_R / R.
20. Compare that with the current you measured in series. The two should agree within the tolerance of the resistor and the accuracy of the meter.
21. Calculate the power dissipated by the resistor, P_R = I squared times R, and confirm it is below the 250 mW rating of a 1/4 W part.
22. Calculate the power dissipated by the LED, P_LED = V_f times I.

A worked example using the nominal figures:

Vs = 5.00 V V_f = 2.00 V R = 330 ohm

V_R = 5.00 - 2.00 = 3.00 V

I = 3.00 / 330 = 9.09 mA

P_R = 0.00909^2 x 330 = 27.3 mW

P_LED= 2.00 x 0.00909 = 18.2 mW

# 8. Result

The LED circuit was assembled and the LED lit from a 5 V supply. The current was limited to approximately 9 mA by a 330 ohm series resistor, which agrees with the value calculated from Ohm’s law. Kirchhoff’s voltage law was verified around the loop, and the resistor power dissipation was confirmed to be well within the rating of a 1/4 W component.

# 9. Precautions

- Never connect an LED to a supply without a series resistor.
- Observe LED polarity. The long lead is the anode and goes towards the positive supply through the resistor.
- Confirm the supply is set to 5 V before switching it on. A higher voltage with the same resistor gives a proportionally higher current.
- Do not exceed the LED maximum forward current, typically 20 mA for a standard 5 mm part.
- Switch the supply off before changing any connection.
- Tighten the screw terminals onto bare conductor, never onto insulation, and tug each wire gently to confirm it is held.
- Check the supply polarity at J1. Reversed supply will simply leave the LED dark in this circuit, but the habit matters once other components are involved.

# 10. Troubleshooting

Symptom | Likely cause | What to do
LED does not light at all | LED connected the wrong way round | Switch off and reverse the LED. The long lead goes to the resistor.
LED does not light at all | Open circuit somewhere in the loop | Measure the voltage at each junction, or check continuity with the supply off.
LED does not light at all | Wire clamped on insulation at J1 | Re-strip the wire and clamp on bare copper.
LED is very dim | Resistor value too high | Confirm the colour code. 3.3 k ohm instead of 330 ohm gives about a tenth of the current.
LED is very dim | Supply voltage too low | Measure Vs at the terminal block, not at the supply front panel.
LED flashes then goes out | Supply current limit tripping | Check for a short across the LED or resistor.
LED lit briefly then dark for good | Resistor missing or short-circuited | The LED has almost certainly failed. Fit a new LED and the correct resistor.
Resistor becomes hot | Resistor value far too low, or supply far too high | Switch off immediately and recalculate the value from section 3.3.

# 11. Review Questions

23. What happens, and why, if the LED is connected the wrong way round in this circuit?
24. Why must the current-limiting resistor be placed in series with the LED rather than in parallel with it?
25. The 330 ohm resistor is replaced with 100 ohm on the same 5 V supply. Calculate the new current, and state whether the LED is within its 20 mA rating.
26. Calculate the resistor needed for a blue LED with a forward voltage of 3.2 V, running at 15 mA from a 5 V supply. Give the nearest standard value.
27. Does it matter whether the resistor is placed on the anode side or the cathode side of the LED? Justify your answer.
28. Why is an LED described as a current-operated device, and what practical difference does that make to how it is driven?
29. The supply is changed from 5 V to 12 V and the resistor is left at 330 ohm. Calculate the new current and the new power dissipated in the resistor. State whether a 1/4 W resistor is still adequate.

Inordinate Industrial Innovations Pvt Ltd.

Restricted www.aid-iot.com

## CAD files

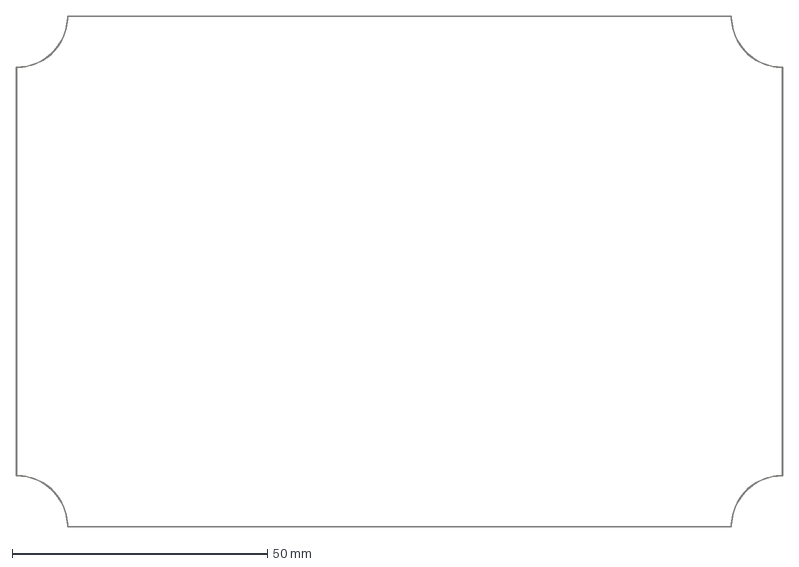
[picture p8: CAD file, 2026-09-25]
hw/export/memento-Edge_Cuts.dxf
150.0 x 100.1 mm

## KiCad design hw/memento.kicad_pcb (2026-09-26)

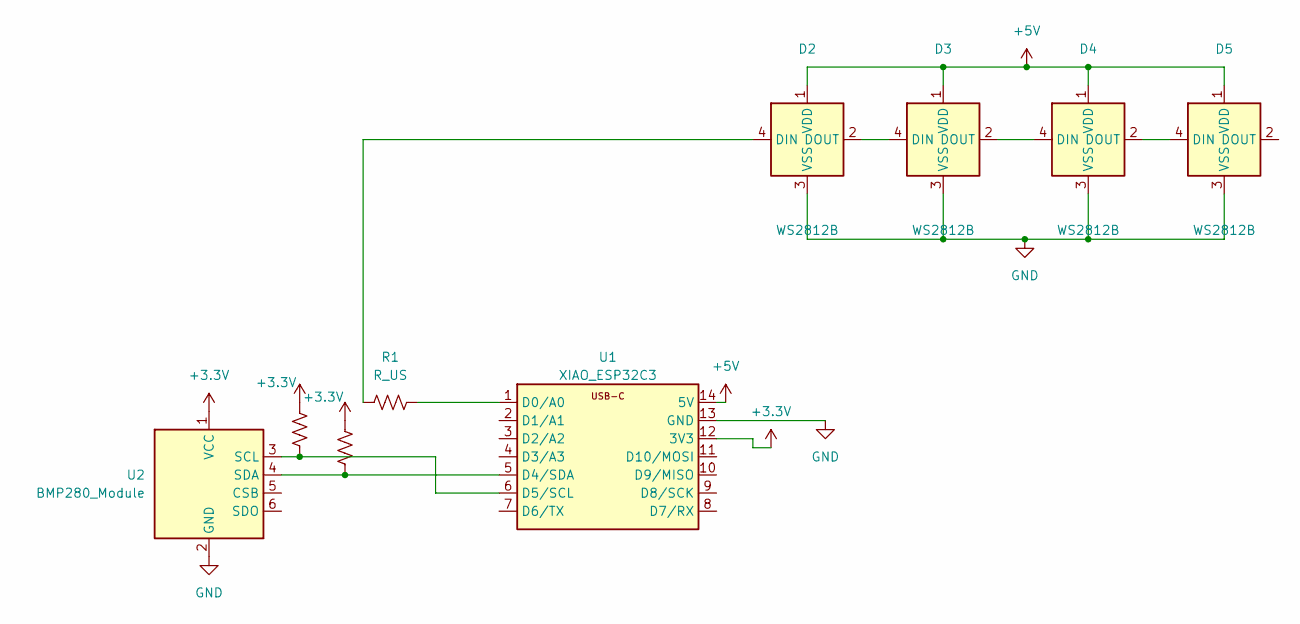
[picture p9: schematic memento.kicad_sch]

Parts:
D2, D3, D4, D5: WS2812B; WS2812B_PLCC4_5.0x5.0mm
R1, R2, R3: R_US; R_0805_2012Metric
U1: XIAO_ESP32C3; XIAO-ESP32C3-Hybrid
U2: BMP280_Module; BMP280_Module_GY_6P_15x11.5mm

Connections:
+3.3V: R2.2, R3.2, U1.12 (3V3), U2.1 (VCC)
+5V: D2.1 (VDD), D3.1 (VDD), D4.1 (VDD), D5.1 (VDD), U1.14 (5V)
GND: D2.3 (VSS), D3.3 (VSS), D4.3 (VSS), D5.3 (VSS), U1.13 (GND), U2.2 (GND)
unnamed: D2.4 (DIN), R1.1
unnamed: D2.2 (DOUT), D3.4 (DIN)
unnamed: D3.2 (DOUT), D4.4 (DIN)
unnamed: D4.2 (DOUT), D5.4 (DIN)
unnamed: R1.2, U1.1 (D0/A0)
unnamed: R3.1, U1.5 (D4/SDA), U2.4 (SDA)
unnamed: R2.1, U1.6 (D5/SCL), U2.3 (SCL)

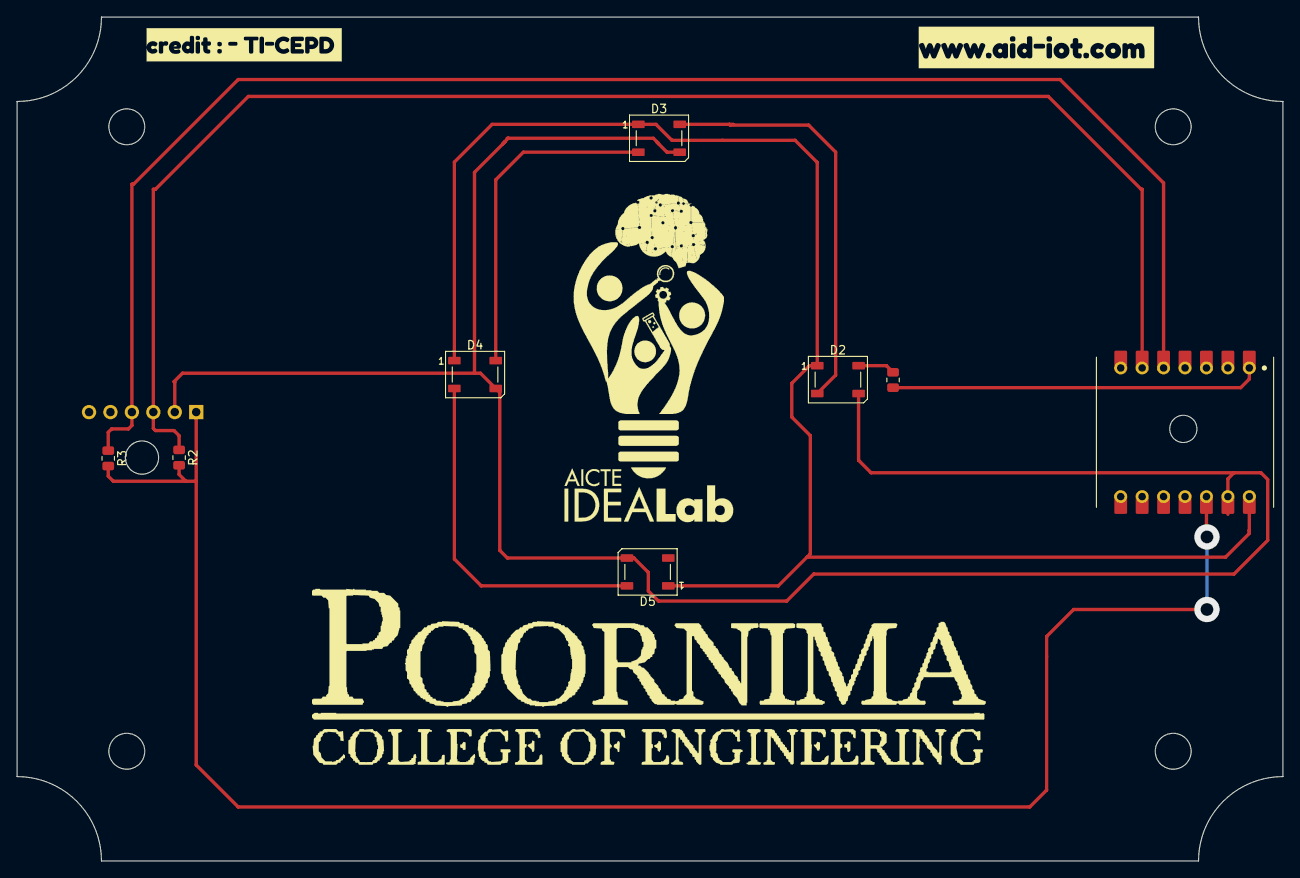
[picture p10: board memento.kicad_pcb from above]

Board: 2 copper layers, 150.0 x 100.0 mm, 13 parts (1 on the bottom side), 10 nets.

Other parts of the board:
LOGO1: Logo_AICTE_IDEALab
LOGO2: Logo_Poornima_80x48
kibuzzard-6AB62C58: G***; kibuzzard-6AB62C58
kibuzzard-6AB62C70: G***; kibuzzard-6AB62C70

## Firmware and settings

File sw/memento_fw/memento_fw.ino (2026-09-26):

/*
 * memento — AICTE IDEA Lab, Poornima College of Engineering
 *
 * Seeed XIAO ESP32C3 + 4x WS2812B + GY-BMP280-3.3 module.
 * Joins your WiFi and serves a page showing the sensor readings and a
 * control for the LEDs.
 *
 * Pin map — read from the schematic (hw/memento.kicad_sch), not guessed:
 *   WS2812B data  XIAO D0 = GPIO2 -> R1 -> D2.DIN -> D3 -> D4 -> D5
 *   I2C SDA       XIAO D4 = GPIO6 -> U2 (BMP280) SDA
 *   I2C SCL       XIAO D5 = GPIO7 -> U2 (BMP280) SCL
 *   Power         +5V and GND from the XIAO
 *
 * Arduino IDE: open this file, pick board "XIAO_ESP32C3", install the
 * libraries listed in ../README.md, edit config.h, upload.
 * PlatformIO:   from the sw/ folder run `pio run -t upload`.
 */

#include <Arduino.h>
#include <WiFi.h>
#include <WebServer.h>
#include <ESPmDNS.h>
#include <Wire.h>
#include <Adafruit_NeoPixel.h>
#include <Adafruit_BMP280.h>

#include "config.h"
#include "index_html.h"

// ------------------------------------------------------------- hardware ---
static const uint8_t  PIN_LED_DATA = 2;  // XIAO D0 / GPIO2
static const uint8_t  PIN_I2C_SDA  = 6;  // XIAO D4 / GPIO6
static const uint8_t  PIN_I2C_SCL  = 7;  // XIAO D5 / GPIO7
static const uint16_t NUM_LEDS     = 4;  // D2 -> D3 -> D4 -> D5

Adafruit_NeoPixel strip(NUM_LEDS, PIN_LED_DATA, NEO_GRB + NEO_KHZ800);
Adafruit_BMP280 bmp;
WebServer server(80);

static bool    bmpOk   = false;
static uint8_t bmpAddr = 0x00;

// ------------------------------------------------------------ LED state ---
enum LedMode { MODE_SOLID, MODE_RAINBOW, MODE_BREATHE, MODE_CHASE, MODE_OFF };

static LedMode  ledMode       = MODE_RAINBOW;
static uint8_t  ledR          = LED_START_R;
static uint8_t  ledG          = LED_START_G;
static uint8_t  ledB          = LED_START_B;
static uint8_t  ledBrightness = LED_START_BRIGHTNESS;
static uint16_t ledSpeed      = 25;  // ms per animation step

static const char *modeName(LedMode m) {
  switch (m) {
    case MODE_SOLID:   return "solid";
    case MODE_RAINBOW: return "rainbow";
    case MODE_BREATHE: return "breathe";
    case MODE_CHASE:   return "chase";
    default:           return "off";
  }
}

static LedMode modeFromName(const String &s) {
  if (s == "solid")   return MODE_SOLID;
  if (s == "rainbow") return MODE_RAINBOW;
  if (s == "breathe") return MODE_BREATHE;
  if (s == "chase")   return MODE_CHASE;
  return MODE_OFF;
}

// ------------------------------------------------------------ animation ---
static void renderLeds() {
  static uint32_t last = 0;
  static uint16_t step = 0;
  uint32_t now = millis();
  if (now - last < ledSpeed) return;
  last = now;
  step++;

  switch (ledMode) {
    case MODE_OFF:
      strip.setBrightness(0);
      strip.clear();
      break;

    case MODE_SOLID:
      strip.setBrightness(ledBrightness);
      for (uint16_t i = 0; i < NUM_LEDS; i++) {
        strip.setPixelColor(i, strip.Color(ledR, ledG, ledB));
      }
      break;

    case MODE_RAINBOW: {
      strip.setBrightness(ledBrightness);
      for (uint16_t i = 0; i < NUM_LEDS; i++) {
        uint16_t hue = (uint16_t)((uint32_t)step * 256UL +
                                  (uint32_t)i * 65536UL / NUM_LEDS);
        strip.setPixelColor(i, strip.gamma32(strip.ColorHSV(hue)));
      }
      break;
    }

    case MODE_BREATHE: {
      // triangle wave 0..255..0, scaled by the brightness setting
      uint8_t phase = (uint8_t)(step & 0xFF);
      uint8_t wave  = phase < 128 ? (uint8_t)(phase * 2)
                                  : (uint8_t)((255 - phase) * 2);
      strip.setBrightness((uint8_t)((uint16_t)wave * ledBrightness / 255));
      for (uint16_t i = 0; i < NUM_LEDS; i++) {
        strip.setPixelColor(i, strip.Color(ledR, ledG, ledB));
      }
      break;
    }

    case MODE_CHASE: {
      strip.setBrightness(ledBrightness);
      uint16_t head = (uint16_t)((step / 4) % NUM_LEDS);
      for (uint16_t i = 0; i < NUM_LEDS; i++) {
        if (i == head) {
          strip.setPixelColor(i, strip.Color(ledR, ledG, ledB));
        } else {
          strip.setPixelColor(i, strip.Color(ledR / 12, ledG / 12, ledB / 12));
        }
      }
      break;
    }
  }
  strip.show();
}

// --------------------------------------------------------------- sensor ---
static bool readSensor(float &tempC, float &hPa, float &altM) {
  if (!bmpOk) return false;
  tempC = bmp.readTemperature();
  hPa   = bmp.readPressure() / 100.0f;
  altM  = bmp.readAltitude(SEA_LEVEL_HPA);
  // a disconnected BMP280 reads back as NaN or a constant 0
  return !isnan(tempC) && !isnan(hPa) && hPa > 1.0f;
}

static bool initSensor() {
  Wire.begin(PIN_I2C_SDA, PIN_I2C_SCL);
  Wire.setClock(100000);
  const uint8_t addrs[] = {0x76, 0x77};
  for (uint8_t i = 0; i < 2; i++) {
    if (bmp.begin(addrs[i])) {
      bmpAddr = addrs[i];
      bmp.setSampling(Adafruit_BMP280::MODE_NORMAL,
                      Adafruit_BMP280::SAMPLING_X2,
                      Adafruit_BMP280::SAMPLING_X16,
                      Adafruit_BMP280::FILTER_X16,
                      Adafruit_BMP280::STANDBY_MS_500);
      Serial.printf("BMP280 found at 0x%02X\n", bmpAddr);
      return true;
    }
  }
  Serial.println("BMP280 NOT found on I2C (checked 0x76 and 0x77)");
  return false;
}

// -------------------------------------------------------------- handlers --
static void handleRoot() {
  server.send_P(200, "text/html", INDEX_HTML);
}

static void handleStatus() {
  float t = 0, p = 0, a = 0;
  bool ok  = readSensor(t, p, a);
  bool sta = (WiFi.status() == WL_CONNECTED);

  String ip = sta ? WiFi.localIP().toString() : WiFi.softAPIP().toString();

  char buf[420];
  snprintf(buf, sizeof(buf),
           "{\"sensor\":{\"ok\":%s,\"address\":%u,"
           "\"temperature_c\":%.2f,\"pressure_hpa\":%.2f,\"altitude_m\":%.2f},"
           "\"led\":{\"mode\":\"%s\",\"r\":%u,\"g\":%u,\"b\":%u,"
           "\"brightness\":%u,\"speed\":%u},"
           "\"net\":{\"mode\":\"%s\",\"ip\":\"%s\",\"rssi\":%d},"
           "\"uptime_s\":%lu}",
           ok ? "true" : "false", (unsigned)bmpAddr,
           ok ? t : 0.0f, ok ? p : 0.0f, ok ? a : 0.0f,
           modeName(ledMode), (unsigned)ledR, (unsigned)ledG, (unsigned)ledB,
           (unsigned)ledBrightness, (unsigned)ledSpeed,
           sta ? "wifi" : "hotspot", ip.c_str(),
           sta ? (int)WiFi.RSSI() : 0,
           (unsigned long)(millis() / 1000));
  server.send(200, "application/json", buf);
}

static uint8_t argByte(const char *name, uint8_t fallback) {
  if (!server.hasArg(name)) return fallback;
  long v = server.arg(name).toInt();
  if (v < 0) v = 0;
  if (v > 255) v = 255;
  return (uint8_t)v;
}

static void handleLed() {
  if (server.hasArg("mode")) ledMode = modeFromName(server.arg("mode"));
  ledR = argByte("r", ledR);
  ledG = argByte("g", ledG);
  ledB = argByte("b", ledB);
  ledBrightness = argByte("brightness", ledBrightness);
  if (server.hasArg("speed")) {
    long v = server.arg("speed").toInt();
    if (v < 5)   v = 5;
    if (v > 200) v = 200;
    ledSpeed = (uint16_t)v;
  }
  server.send(200, "application/json", "{\"ok\":true}");
}

static void handleNotFound() {
  server.send(404, "text/plain", "not found");
}

// ---------------------------------------------------------------- setup ---
static void startNetwork() {
  WiFi.mode(WIFI_STA);
  WiFi.setHostname(MDNS_HOSTNAME);
  WiFi.begin(WIFI_SSID, WIFI_PASSWORD);
  Serial.printf("Joining \"%s\" ", WIFI_SSID);

  uint32_t t0 = millis();
  while (WiFi.status() != WL_CONNECTED && millis() - t0 < WIFI_TIMEOUT_MS) {
    delay(250);
    Serial.print('.');
  }
  Serial.println();

  if (WiFi.status() == WL_CONNECTED) {
    Serial.printf("Connected. Open http://%s/  (or http://%s.local/)\n",
                  WiFi.localIP().toString().c_str(), MDNS_HOSTNAME);
  } else {
    Serial.println("Could not join that network - starting hotspot instead.");
    WiFi.mode(WIFI_AP);
    WiFi.softAP(AP_SSID, strlen(AP_PASSWORD) >= 8 ? AP_PASSWORD : NULL);
    Serial.printf("Hotspot \"%s\" -> open http://%s/\n",
                  AP_SSID, WiFi.softAPIP().toString().c_str());
  }

  if (MDNS.begin(MDNS_HOSTNAME)) MDNS.addService("http", "tcp", 80);
}

void setup() {
  Serial.begin(115200);
  delay(300);
  Serial.println("\nmemento starting");

  strip.begin();
  strip.setBrightness(ledBrightness);
  strip.clear();
  strip.show();
  ledMode = modeFromName(String(LED_START_MODE));

  bmpOk = initSensor();

  startNetwork();

  server.on("/", handleRoot);
  server.on("/api/status", handleStatus);
  server.on("/api/led", handleLed);
  server.onNotFound(handleNotFound);
  server.begin();
  Serial.println("HTTP server up on port 80");
}

void loop() {
  server.handleClient();
  renderLeds();

  // if the sensor was missing at boot, retry occasionally so a late or loose
  // connection still comes up without a power cycle
  static uint32_t lastTry = 0;
  if (!bmpOk && millis() - lastTry > 5000) {
    lastTry = millis();
    bmpOk = initSensor();
  }
}

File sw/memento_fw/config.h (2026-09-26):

/*
 * memento — user configuration
 *
 * Edit the two WiFi lines below, then upload. Nothing else in here has to
 * change for the board to work.
 */
#ifndef MEMENTO_CONFIG_H
#define MEMENTO_CONFIG_H

// ---------------------------------------------------------------- WiFi ----
// Put your network name and password here.
#define WIFI_SSID       "YOUR_WIFI_NAME"
#define WIFI_PASSWORD   "YOUR_WIFI_PASSWORD"

// How long to wait for the network before giving up, in milliseconds.
#define WIFI_TIMEOUT_MS 20000

// If the network above cannot be joined, the board starts its own hotspot
// with these credentials so the page is still reachable.
// An open hotspot is possible by setting AP_PASSWORD to "" — otherwise the
// password must be at least 8 characters.
#define AP_SSID         "memento-setup"
#define AP_PASSWORD     "memento123"

// Reachable as http://memento.local/ on networks that support mDNS.
#define MDNS_HOSTNAME   "memento"

// ------------------------------------------------------------- sensor ----
// Local sea-level pressure in hPa. The altitude reading is only as good as
// this number; 1013.25 is the standard-atmosphere default.
#define SEA_LEVEL_HPA   1013.25f

// -------------------------------------------------------------- LEDs -----
// Startup appearance. Modes: "solid", "rainbow", "breathe", "chase", "off".
#define LED_START_MODE       "rainbow"
#define LED_START_BRIGHTNESS 60     // 0-255
#define LED_START_R          0
#define LED_START_G          120
#define LED_START_B          255

#endif  // MEMENTO_CONFIG_H

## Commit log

2026-09-25 Initial commit: memento KiCad project
    Board: 150 x 100 mm, XIAO ESP32C3 module driving an 0805 LED + resistor.
    Project library (memento):
    - XIAO_ESP32C3 symbol and XIAO-ESP32C3-Hybrid footprint (14 THT holes on
    2.54 mm pitch / 15.24 mm rows, each with an outboard castellation pad).
    Geometry taken from Seeed's official land pattern.
    - WS2812B symbol and PLCC-4 5.0x5.0 mm footprint. Pinout (1=VDD 2=DOUT
    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
    [memento-Edge_Cuts.dxf, memento.kicad_pcb, memento.kicad_sch]
2026-09-25 Add KiBuzzard silkscreen label footprint to board
    [memento.kicad_pcb]
2026-09-25 pcb updated
    [memento.kicad_pcb, memento.kicad_sch]
2026-09-26 routing updated
    [memento.kicad_pcb, memento.kicad_sch]
2026-09-26 memento updated
    [memento.kicad_pcb]
2026-09-26 sw created
    [memento-Edge_Cuts.dxf, memento.kicad_pcb, memento.kicad_sch]
2026-09-26 files updated
    [memento.kicad_pcb, memento.kicad_sch]
2026-09-26 kicad added
